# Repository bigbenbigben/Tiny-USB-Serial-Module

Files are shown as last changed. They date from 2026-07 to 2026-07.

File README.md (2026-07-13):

# UIAPduino対応 CP2102N搭載 小型USBシリアル変換モジュール

[日本語](README.md) | [English](README_EN.md)

## 概要

<div class="image-row">
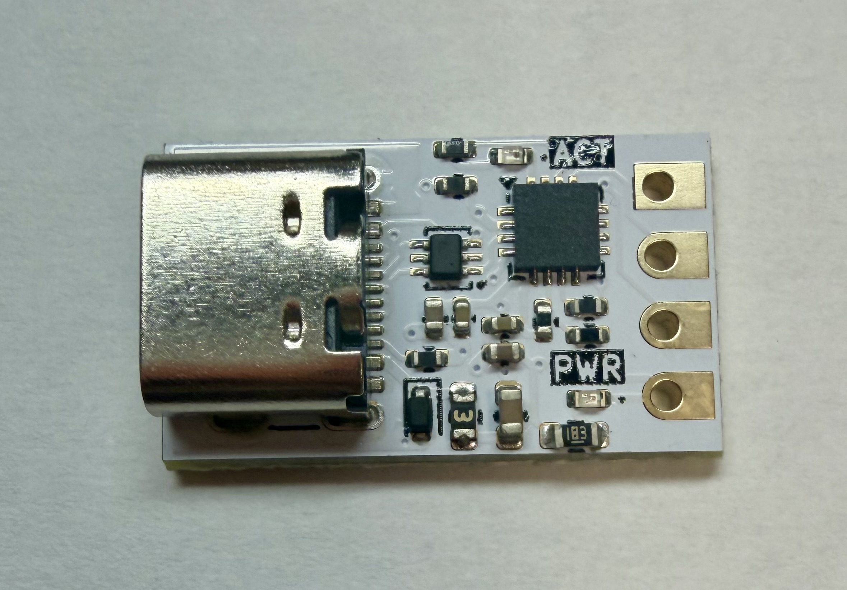
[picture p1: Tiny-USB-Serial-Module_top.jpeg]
    
    &nbsp;&nbsp;&nbsp;&nbsp;
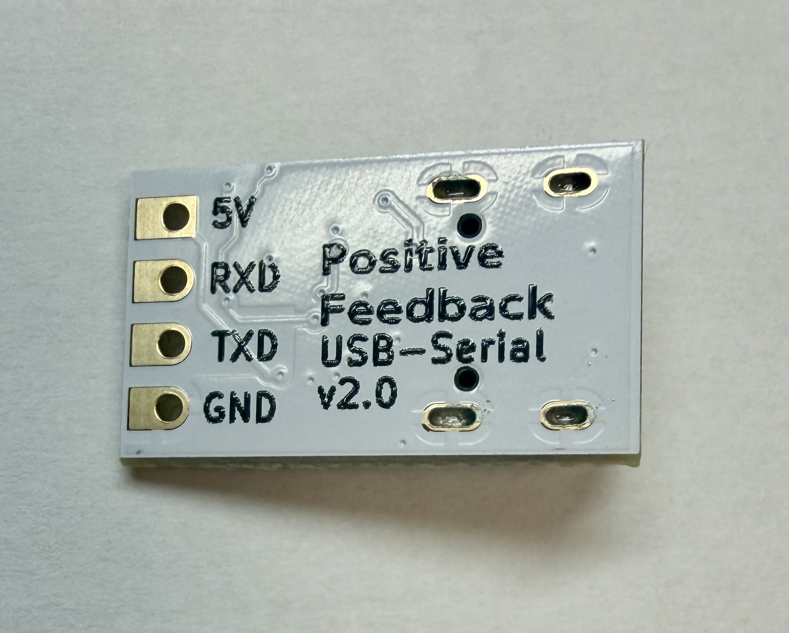
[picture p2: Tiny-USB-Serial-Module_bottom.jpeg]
    
</div>

Silicon Labs社のCP2102Nを採用した、基板サイズ20mm×12mmの小型USBシリアル変換基板です。

USB Type-C接続、USBバスパワー動作に対応しており、TxD、RxDはスルーホール端子から引き出しています。

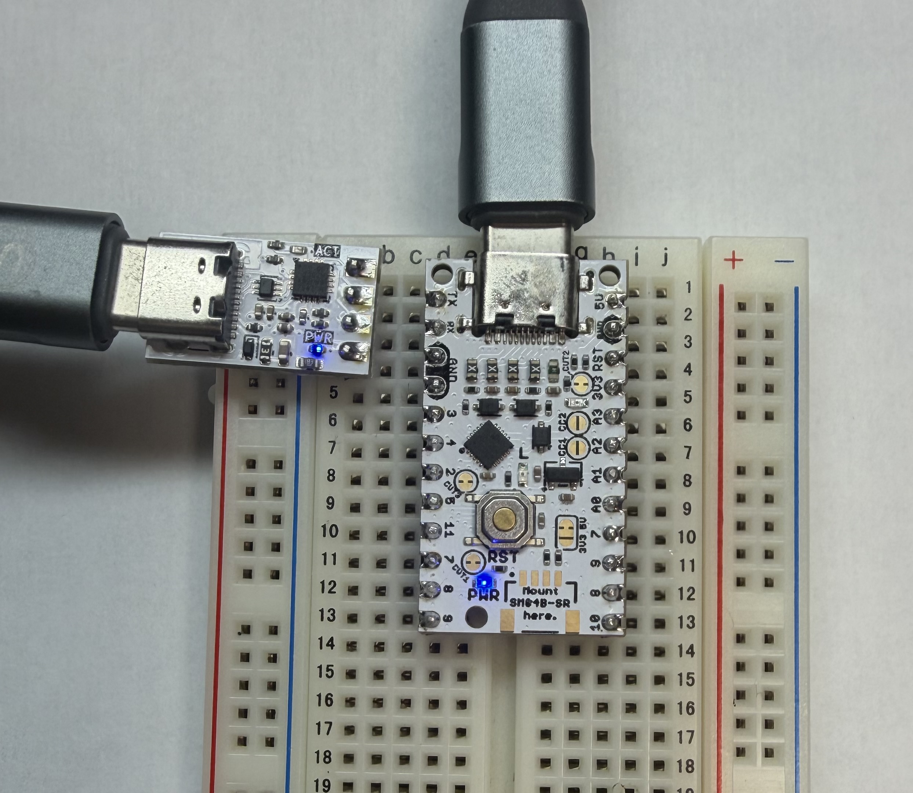
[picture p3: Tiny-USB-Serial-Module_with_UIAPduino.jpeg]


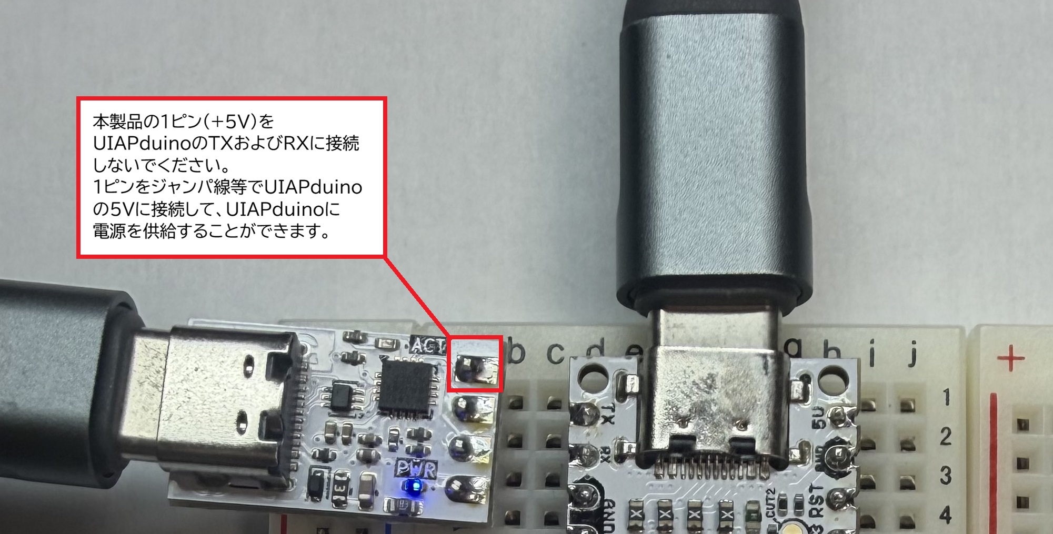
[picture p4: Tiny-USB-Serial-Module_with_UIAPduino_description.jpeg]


本基板は[UIAPduino Pro Micro CH32V003 V1.4](https://www.uiap.jp/uiapduino/pro-micro/ch32v003/v1dot4)のピン配置に対応しており、コンスルーやブレッドボードによりRXD、TXD、GNDをそのまま接続することができます。

## サイズ

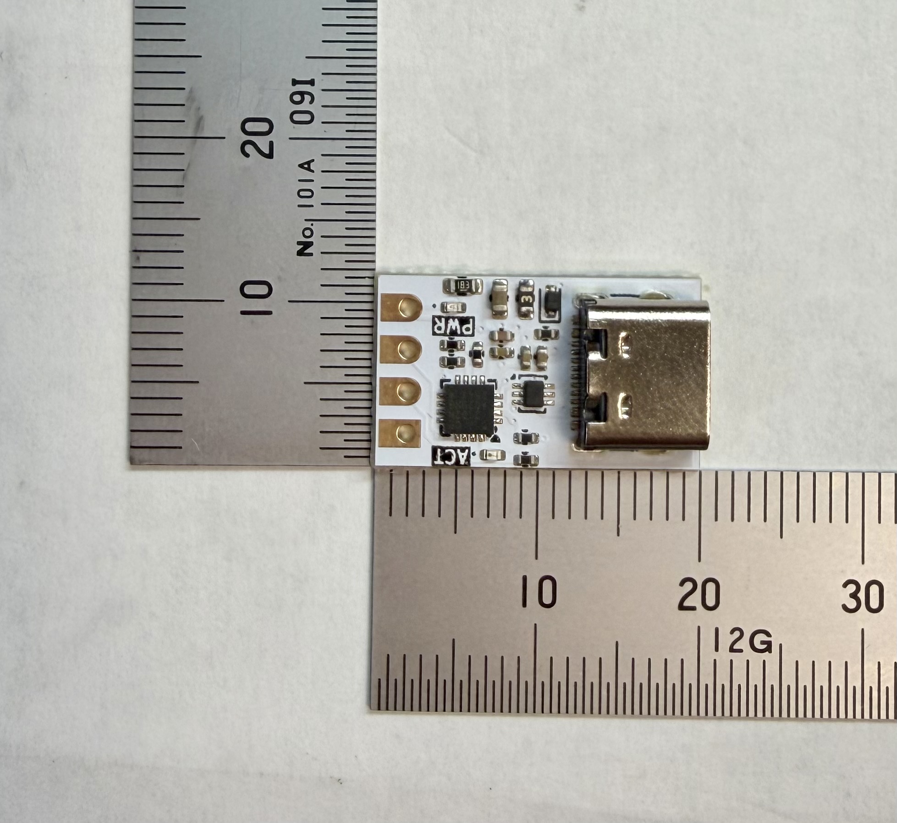
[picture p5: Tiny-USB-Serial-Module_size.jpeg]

基板サイズ：20mm×12mm
高さ：5mm（実測値）
重量：1.3g

## 特徴

- 小型です。（基板サイズ20mm×12mm）
- Silicon Labs社のCP2102Nを使用。
- 過電流保護回路搭載。
- 静電気対策回路搭載。
- USB Type-Cコネクタ搭載。
- USBバスパワー動作。
- 入力5Vトレラント。
- UIAPduinoにそのまま挿入できるピン配置になっています。
- RoHS対応です。

## 主な仕様

- 電源電圧Max.：5V
- IO電圧Max.：3.3V（入力5Vトレラント）
- ボーレートMin.：300bps
- ボーレートMax.：3Mbps
- 受信バッファ：512バイト
- 送信バッファ：512バイト
- LED 2個（電源：青、TxD：オレンジ）

## ピン配置

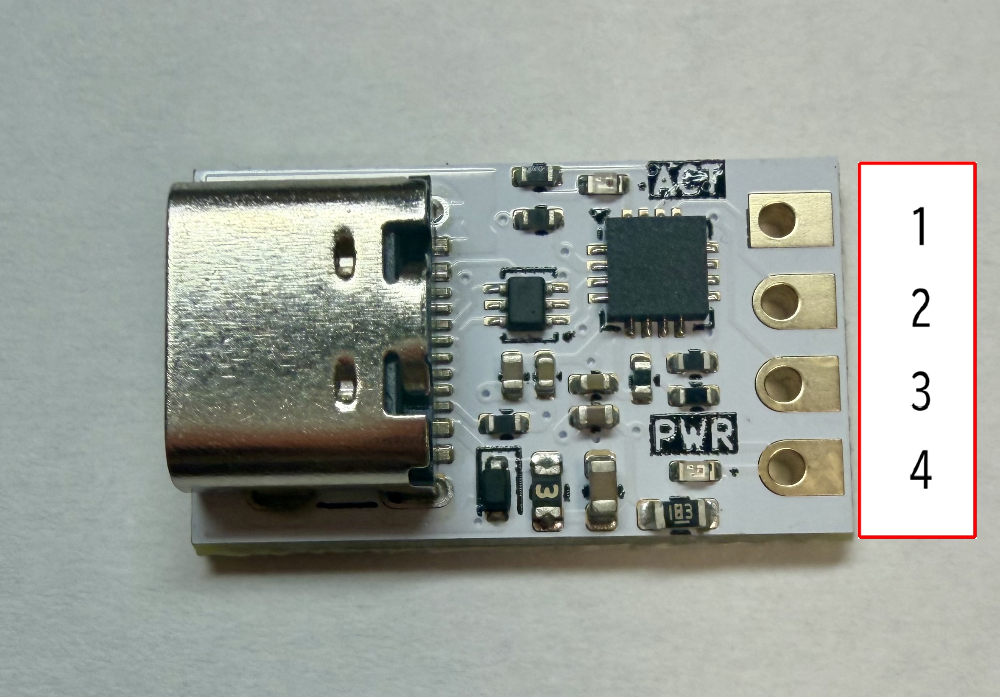
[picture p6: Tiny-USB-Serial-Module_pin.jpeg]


- p1 ： +5V(VBUS)
- p2 ： RXD
- p3 ： TXD
- p4 ： GND

## 対応OS

本製品に使用しているCP2102Nは以下のOS向けにドライバが提供されています。

対象OS：Windows, macOS, Linux, and Android

ドライバ提供サイト：[https://www.silabs.com/software-and-tools/usb-to-uart-bridge-vcp-drivers?tab=downloads](https://www.silabs.com/software-and-tools/usb-to-uart-bridge-vcp-drivers?tab=downloads)

筆者は Windows 11 Pro 25H2 で動作を確認しています。

## 注意

- RXDは5V入力対応、TXDは3.3V出力です。一般的な5Vマイコンでは問題なく使用できますが、5Vロジック入力を必須とする機器には対応していません。
- TXD/RXDの接続には注意してください。例としてUART接続では、TXDとRXDをクロス接続します。本製品のTXDを相手機器のRXDへ、本製品のRXDを相手機器のTXDへ接続してください。
- 2026/7/12現在、UIAPduinoは`Serial.available()`が動かないようです。筆者は[UIAPSerial](https://github.com/tarosay/sdlog_uiapduino/tree/main/SDLog)というライブラリで動作確認しました。

## Author

ポジティブフィードバック
bigben (@bigbenbigben)

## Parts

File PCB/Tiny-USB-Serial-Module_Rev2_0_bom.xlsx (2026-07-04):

Tiny-USB-Serial-Module BOM
Rev | 2
June 7, 2026 at 15:00
Reference | Qty | PART | Value | VAL1 | VAL2 | LCSC Part #
C1 | 1 | CL10A106KP8NNNC | 10uF | 10V | 10% | C19702
C2,C3 | 2 | CL05B104KO5NNNC | 0.1uF | 16V | 10% | C1525
C4,C5 | 2 | CL05A475MP5NRNC | 4.7uF | 10V | 20% | C23733
CN1 | 1 | UC09-0B16F00P11 | UC09-0B16F00P11 |  |  | C36936538
D1 | 1 | ESD5Z5V0 | ESD5Z5V0 |  |  | C85708
D2 | 1 | XL-1005UBC | XL-1005UBC | BLUE |  | C22355736
D3 | 1 | XL-1005UOC | XL-1005UOC | ORANGE |  | C965791
D4 | 1 | USBLC6-2P6 | USBLC6-2P6 |  |  | C15999
F1 | 1 | JK-SMD0603-035-6 | JK-SMD0603-035-6 | 350mA |  | C2832202
R1 | 1 | 0603WAF1802T5E | 18k | 1% |  | C25810
R2,R3,R4 | 3 | 0402WGF5101TCE | 5.1k | 1% |  | C25905
R5 | 1 | RTT022212FTH | 22.1k | 1% |  | C102896
R6 | 1 | CR0402FF4752G | 47.5k | 1% |  | C100449
R7 | 1 | 0402WGF1001TCE | 1k | 5% |  | C11702
U1 | 1 | CP2102N-A02-GQFN20R | CP2102N-A02-GQFN20R |  |  | C969913

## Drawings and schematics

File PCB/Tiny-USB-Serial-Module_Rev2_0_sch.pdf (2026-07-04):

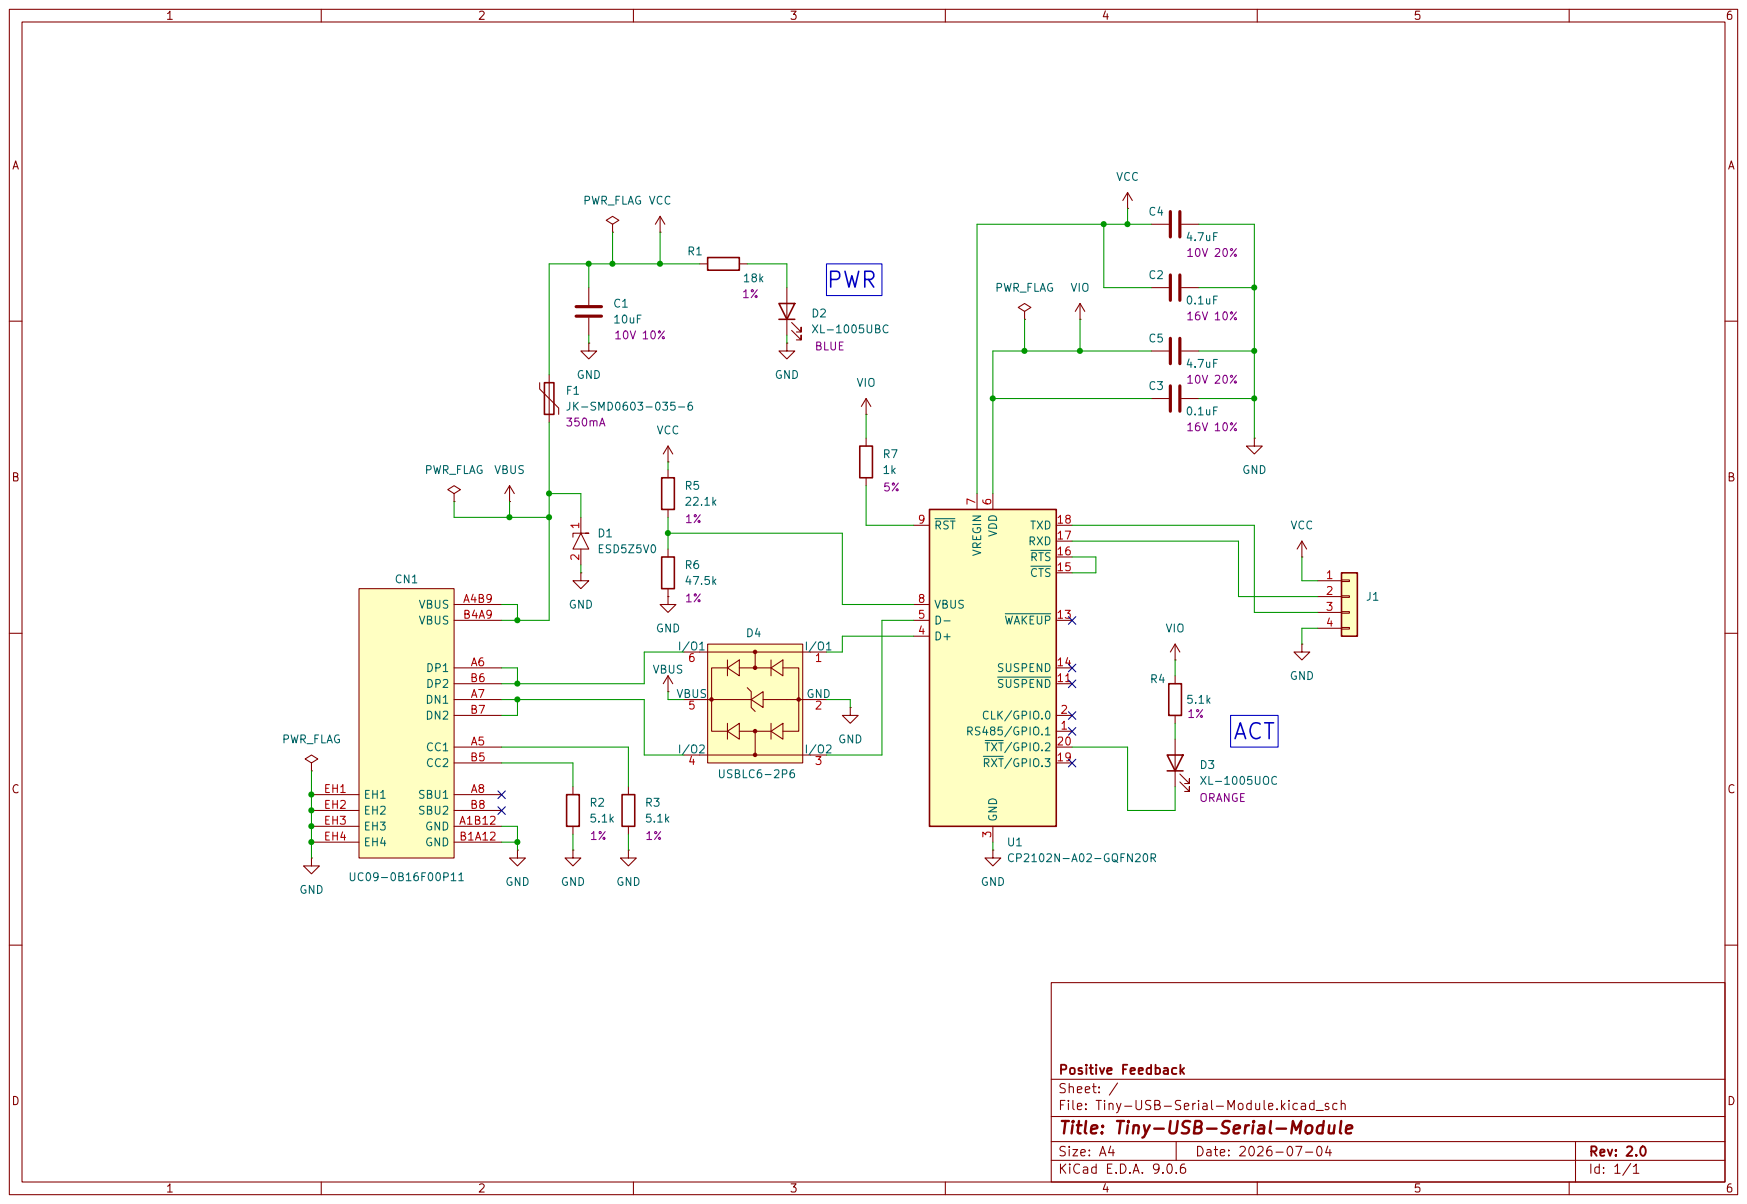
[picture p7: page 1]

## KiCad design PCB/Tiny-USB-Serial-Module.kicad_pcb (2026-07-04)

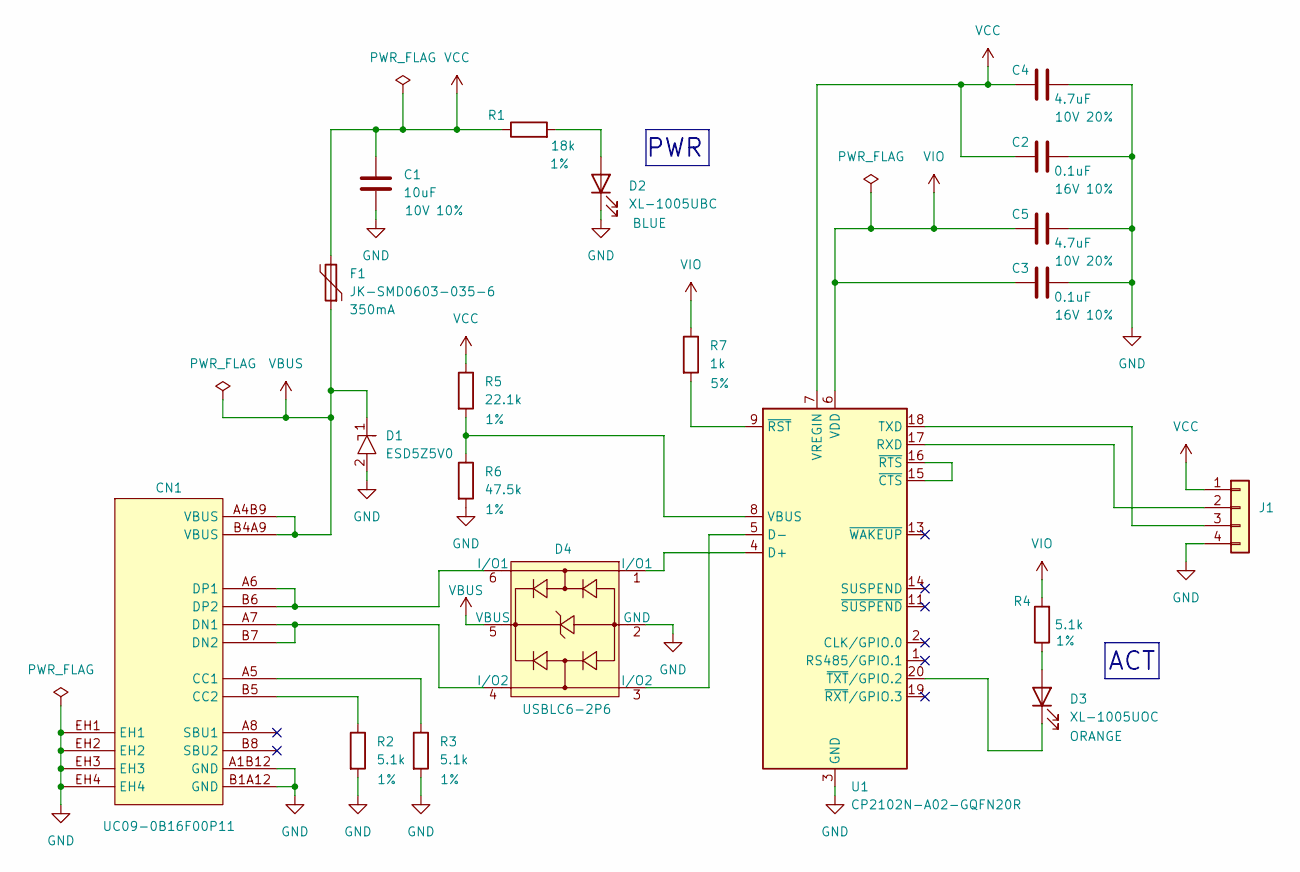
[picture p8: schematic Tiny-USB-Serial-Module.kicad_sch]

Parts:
C1: 10uF; C_0603_1608Metric; PART CL10A106KP8NNNC; LCSC Part # C19702
C2, C3: 0.1uF; C_0402_1005Metric; PART CL05B104KO5NNNC; LCSC Part # C1525
C4, C5: 4.7uF; C_0402_1005Metric; PART CL05A475MP5NRNC; LCSC Part # C23733
CN1: UC09-0B16F00P11; USB_C_Receptacle_UC09-0B16F00P11; PART UC09-0B16F00P11; LCSC Part # C36936538
D1: ESD5Z5V0; D_SOD-523; PART ESD5Z5V0; LCSC Part # C85708
D2: XL-1005UBC; LED_0402_1005Metric; PART XL-1005UBC; LCSC Part # C22355736
D3: XL-1005UOC; LED_0402_1005Metric; PART XL-1005UOC; LCSC Part # C965791
D4: USBLC6-2P6; SOT-666; PART USBLC6-2P6; LCSC Part # C15999
F1: JK-SMD0603-035-6; Fuse_0603_1608Metric; PART JK-SMD0603-035-6; LCSC Part # C2832202
J1: Conn_01x04; Pad_1x04_P2.54mm
R1: 18k; R_0603_1608Metric; PART 0603WAF1802T5E; LCSC Part # C25810
R2, R3, R4: 5.1k; R_0402_1005Metric; PART 0402WGF5101TCE; LCSC Part # C25905
R5: 22.1k; R_0402_1005Metric; PART RTT022212FTH; LCSC Part # C102896
R6: 47.5k; R_0402_1005Metric; PART CR0402FF4752G; LCSC Part # C100449
R7: 1k; R_0402_1005Metric; PART 0402WGF1001TCE; LCSC Part # C11702
U1: CP2102N-A02-GQFN20R; SiliconLabs_QFN-20-1EP_3x3mm_P0.5mm_EP1.8x1.8mm; PART CP2102N-A02-GQFN20R; LCSC Part # C969913

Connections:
GND: C1.2, C2.2, C3.2, C4.2, C5.2, CN1.A1B12 (GND), CN1.B1A12 (GND), CN1.EH1, CN1.EH2, CN1.EH3, CN1.EH4, D1.2 (A), D2.1 (K), D4.2 (GND), J1.4, R2.2, R3.2, R6.2, U1.3 (GND), U1.12 (GND), U1.21 (GND)
unnamed: CN1.A5 (CC1), R3.1
unnamed: CN1.B5 (CC2), R2.1
unnamed: CN1.A7 (DN1), CN1.B7 (DN2), D4.4 (I/O2)
unnamed: CN1.A6 (DP1), CN1.B6 (DP2), D4.6 (I/O1)
unnamed: D2.2 (A), R1.2
unnamed: D3.2 (A), R4.1
unnamed: D3.1 (K), U1.20 (~TXT/GPIO.2)
unnamed: J1.2, U1.17 (RXD)
unnamed: J1.3, U1.18 (TXD)
unnamed: D4.1 (I/O1), U1.4 (D+)
unnamed: D4.3 (I/O2), U1.5 (D-)
unnamed: R5.2, R6.1, U1.8 (VBUS)
unnamed: U1.15 (~CTS), U1.16 (~RTS)
unnamed: R7.2, U1.9 (~RST)
VBUS: CN1.A4B9 (VBUS), CN1.B4A9 (VBUS), D1.1 (K), D4.5 (VBUS), F1.1
VCC: C1.1, C2.1, C4.1, F1.2, J1.1, R1.1, R5.1, U1.7 (VREGIN)
VIO: C3.1, C5.1, R4.2, R7.1, U1.6 (VDD)

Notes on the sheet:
ACT
PWR

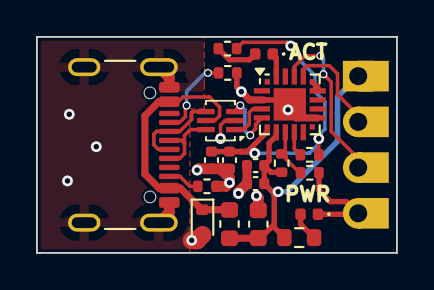
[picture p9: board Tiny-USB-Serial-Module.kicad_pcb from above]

Board: 2 copper layers, 20.0 x 12.0 mm, 20 parts (0 on the bottom side), 18 nets.

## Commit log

2026-07-08 Add README notes on TXD level and TXD/RXD wiring
    - Clarify that TXD outputs 3.3V logic
    - Explain cross-wiring between TXD and RXD for UART connections
2026-07-13 Update dimensions section in README_EN.md
    Added board size and weight information to README.
